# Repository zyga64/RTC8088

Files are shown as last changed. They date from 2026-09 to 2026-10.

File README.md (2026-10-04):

# RTC8088
Real Time Clock for your PC XT. Very low profile, simple and open hardware.

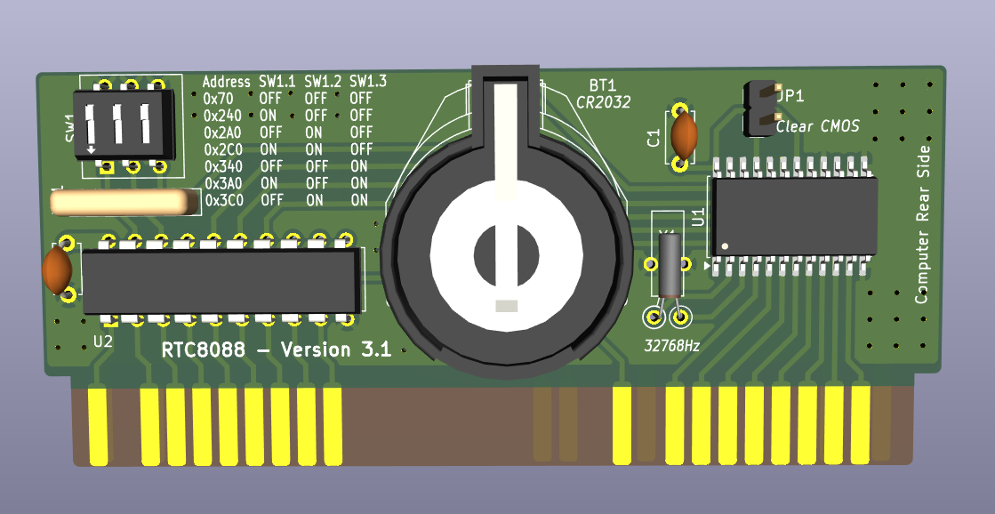
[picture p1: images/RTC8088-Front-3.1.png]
RTC8088 V3.1 3D Rendering


## Hardware Documentation

### Schematic and PCB Layout

[Schematic - Version 3.1](KiCad/RTC8088-Schematic-3.1.pdf)

### Swiches and Jumpers

#### SW1 - RTC I/O address select

I/O Address  | SW1.1 | SW 1.2 | SW 1.3
------------ | ----- | ------ | ------
0x70         | OFF   | OFF    | OFF
0x240        | ON    | OFF    | OFF
0x2A0        | OFF   | ON     | OFF
0x2C0        | ON    | ON     | OFF
0x340        | OFF   | OFF    | ON
0x3A0        | ON    | OFF    | ON
0x3C0        | OFF   | ON     | ON
Reserved     | ON    | ON     | ON

* Note 1: The table above gives the addresses in the supplied SPLD fuse map. The selection can be changed by reprogramming the SPLD
* Note 2: "Reserved" address is set to 0x70 in the supplied SPLD fuse map. It is recommended to use this setting when adding a custom I/O address to the SPLD

#### JP1 - Clear CMOS

Position       | Description
-------------- | -----------------
open (default) | Normal operation
closed         | Clear NVRAM memory

### Bill of Materials

#### Version 3.1

Component type     | Reference | Description                                     | Quantity | Possible sources and notes 
------------------ | --------- | ----------------------------------------------- | -------- | --------------------------
PCB                |           | RTC8088 PCB - Version 3.0                       | 1        | Order from your favorite PCB manufacturer using provided Gerber files
Integrated Circuit | U1        | BQ3285S - RTC, 24 pin SO -24                    | 1        | Aliexpress :)
Integrated Circuit | U2        | ATF16V8B-15PU - Simple Programmable Logic Device, 20 pin DIP | 1 | Mouser [556-AF16V8B15PU](https://www.mouser.com/ProductDetail/556-AF16V8B15PU) or GAL16V8
Quartz Crystal     | Y1        | 32768 Hz, 6 pF                                  | 1        | Mouser [815-AB26T32768KHZ6B](https://www.mouser.com/ProductDetail/815-AB26T32768KHZ6B), [520-ECS327-6-13-X](https://www.mouser.com/ProductDetail/520-ECS327-6-13-X), or [628-VT200F-6PF20PPM](https://www.mouser.com/ProductDetail/628-VT200F-6PF20PPM)
Battery Holder     | BT1       | CR2032 battery holder                           | 1        | Mouser [122-2620-GR](https://www.mouser.com/ProductDetail/122-2620-GR) or [122-2420-GR](https://www.mouser.com/ProductDetail/122-2420-GR)
Battery            | BT1       | CR2032 battery                                  | 1        | Mouser [81-CR2032](https://www.mouser.com/ProductDetail/81-CR2032), [658-CR2032](https://www.mouser.com/ProductDetail/658-CR2032), or [614-CR2032-200](https://www.mouser.com/ProductDetail/614-CR2032-200)
Capacitor          | C1,C2     | 0.1 uF, 50V, MLCC, 5 mm pitch                   | 2        | Mouser [594-K104K15X7RF53H5](https://www.mouser.com/ProductDetail/594-K104K15X7RF53H5) or [810-FG28X7R1H104KNT6](https://www.mouser.com/ProductDetail/810-FG28X7R1H104KNT6)
Resistor Array     | RN1       | 10 kohm, bussed, 5 pin SIP                      | 1        | Mouser [652-4605X-1LF-10K](https://www.mouser.com/ProductDetail/652-4605X-1LF-10K) or [652-4605X-AP1-103LF](https://www.mouser.com/ProductDetail/652-4605X-AP1-103LF)
DIP Switch         | SW1       | DIP switch, 3 position, SPST                    | 1        | Mouser [774-2103MS](https://www.mouser.com/ProductDetail/774-2103MS)
Pin Header         | JP1       | 2 pin header, 2.54 mm pitch                     | 1        | Mouser [649-68002-102HLF](https://www.mouser.com/ProductDetail/649-68002-102HLF)
Jumper             | JP1       | Shunt, 2 pin, 2.54 mm pitch                     | 1        | Mouser [806-SX1100-B](https://www.mouser.com/ProductDetail/806-SX1100-B)
IC Socket          | U2        | 20 pin DIP, 2.54 mm pitch, 7.62 mm row spacing  | 1        | Mouser [649-DILB20P-223TLF](https://www.mouser.com/ProductDetail/649-DILB20P-223TLF)

## Software

The board is supported by the [8088 BIOS](https://github.com/skiselev/8088_bios) and [GLaTICK BIOS Extension](https://github.com/640-KB/GLaTICK).

## Release Notes

### Changes

* Version 3.1
  * Change THT DS12885 to SMT BQ3285S
* Version 3.0
  * Add I/O address configuration switches
  * Remove IRQ configuration jumpers and IRQ support
* Version 2.0
  * Aitor RTC8088
* Version 1.0
  * Initial version

### Known Issues

* No known issues

### Wishlist

* None so far

## Red Tape

### Licensing

RTC8088 is an open source hardware project. The hardware design itself, including schematic and PCB layout design files are licensed under the strongly-reciprocal variant of [CERN Open Hardware Licence version 2](license-cern_ohl_s_v2.txt). The SPLD code is licensed under [GNU General Public License v3](license-gpl-3.0.txt). Documentation, including this file, is licensed under the [Creative Commons Attribution-ShareAlike 4.0 International License](license-cc-by-sa-4.0.txt).

CERN-OHL-2.0-S, GPL-3.0, CC-BY-SA-4.0

## More information

### Orignal RTC8088 Project Description
https://hackaday.io/project/168972-rtc-isa-8-bits-pcxt

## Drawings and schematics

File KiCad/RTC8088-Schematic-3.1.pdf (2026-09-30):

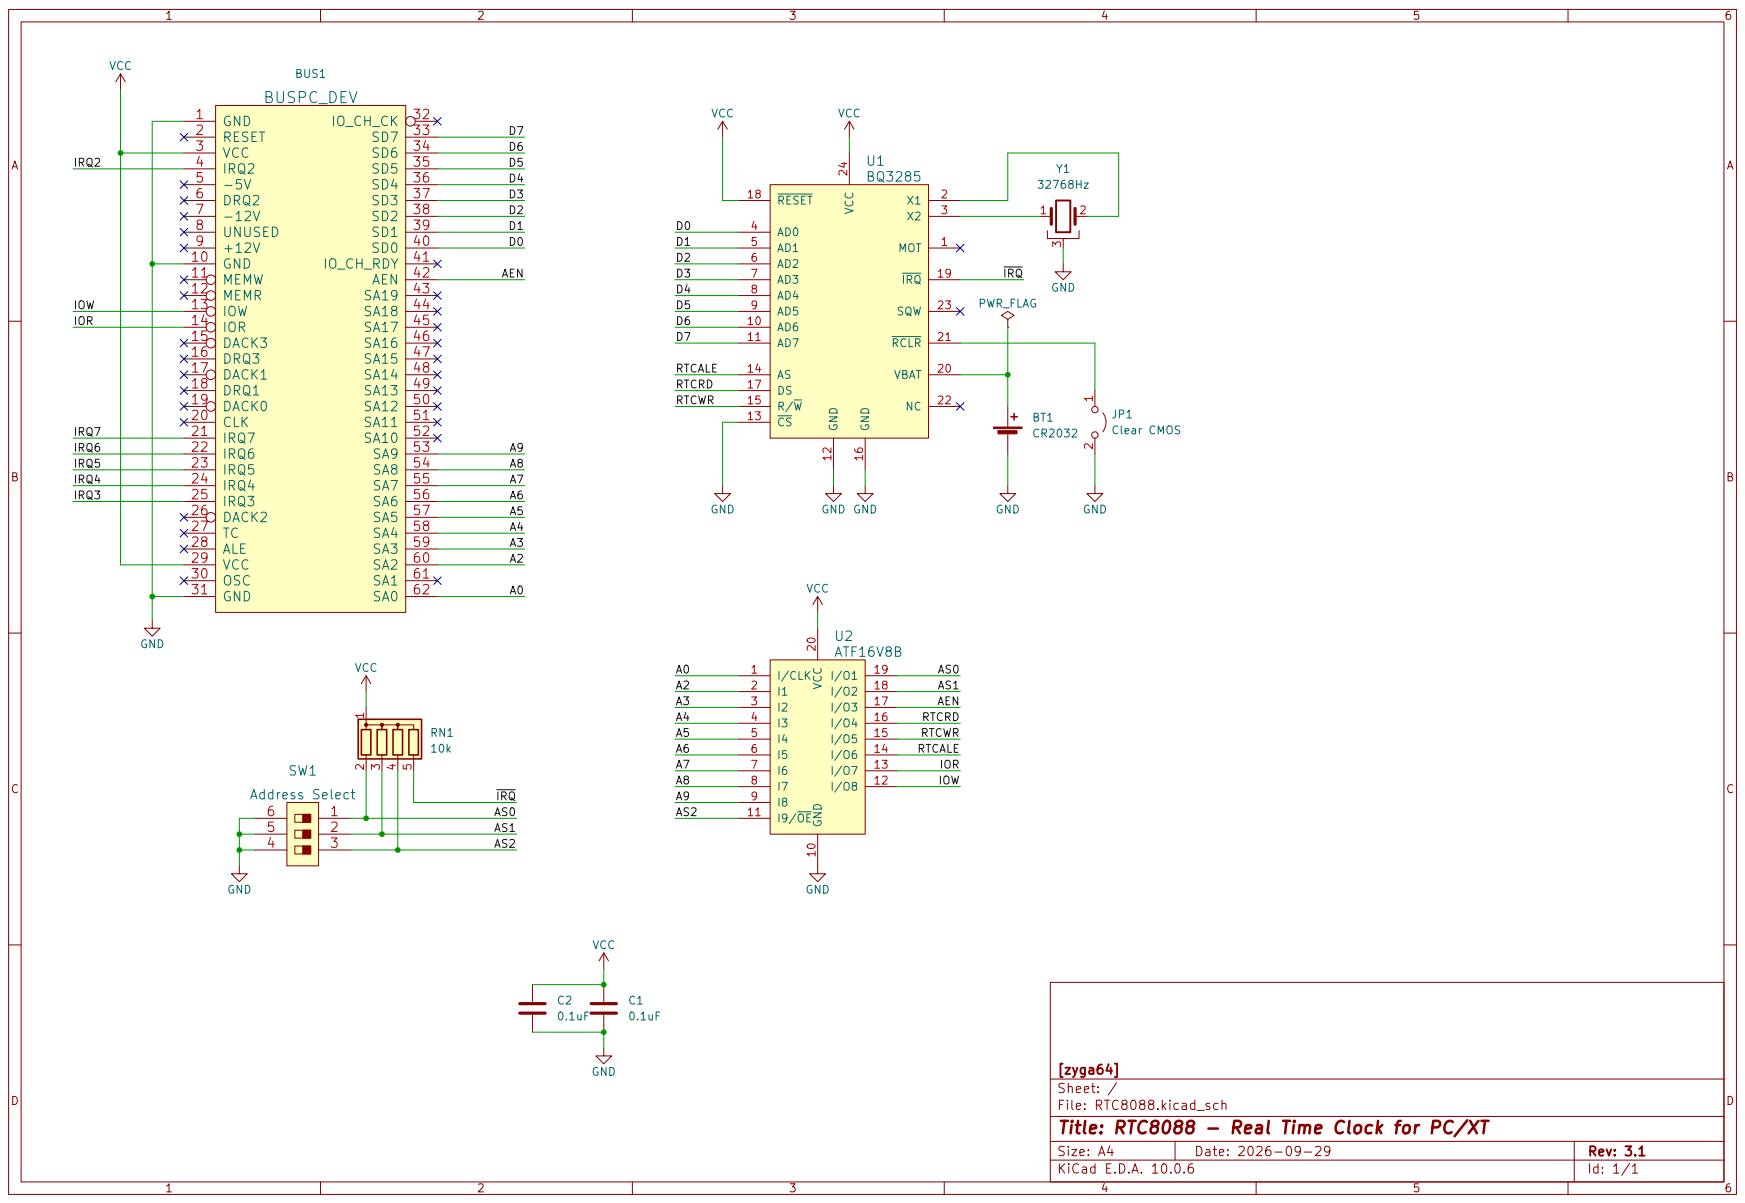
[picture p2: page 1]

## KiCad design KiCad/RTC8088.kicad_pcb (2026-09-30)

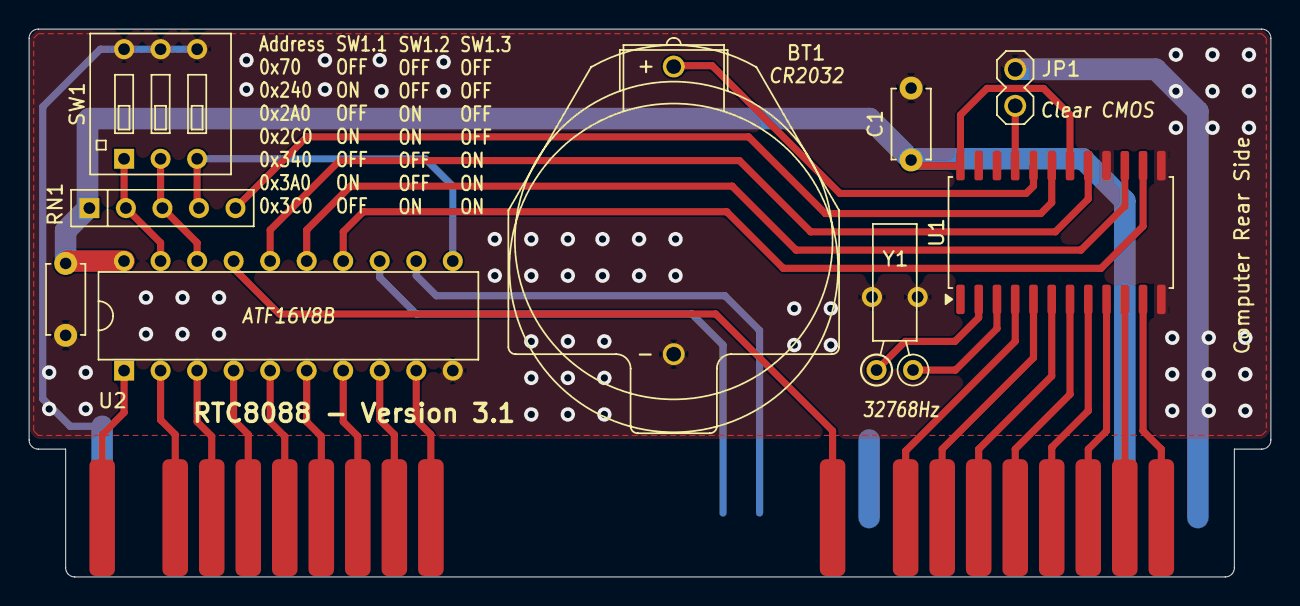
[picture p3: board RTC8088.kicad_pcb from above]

Board: 2 copper layers, 86.4 x 38.1 mm, 10 parts (0 on the bottom side), 33 nets.

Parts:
BT1: CR2032; Battery_Holder_CR2032_Universal
BUS1: BUSPC_DEV; Conn_Edge_PCB_ISA8
C1, C2: 0.1uF; C_Disc_D4.7mm_W2.5mm_P5.00mm
JP1: Clear CMOS; Conn_Pin_Header_2x1_2.54mm_NoKey
RN1: 10k; Conn_SIL5
SW1: Address Select; Switch_DIP_3_Positions
U1: DS12885; SOIC-24W_7.5x15.4mm_P1.27mm
U2: ATF16V8B; IC_DIP20_300
Y1: 32768Hz; Crystal_32K_Horiz

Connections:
/A0: BUS1.62 (SA0), U2.1 (I/CLK)
/A2: BUS1.60 (SA2), U2.2 (I1)
/A3: BUS1.59 (SA3), U2.3 (I2)
/A4: BUS1.58 (SA4), U2.4 (I3)
/A5: BUS1.57 (SA5), U2.5 (I4)
/A6: BUS1.56 (SA6), U2.6 (I5)
/A7: BUS1.55 (SA7), U2.7 (I6)
/A8: BUS1.54 (SA8), U2.8 (I7)
/A9: BUS1.53 (SA9), U2.9 (I8)
/AEN: BUS1.42 (AEN), U2.17 (I/O3)
/AS0: RN1.2 (R1), SW1.1, U2.19 (I/O1)
/AS1: RN1.3 (R2), SW1.2, U2.18 (I/O2)
/AS2: RN1.4 (R3), SW1.3, U2.11 (I9/~OE)
/D0: BUS1.40 (SD0), U1.4 (AD0)
/D1: BUS1.39 (SD1), U1.5 (AD1)
/D2: BUS1.38 (SD2), U1.6 (AD2)
/D3: BUS1.37 (SD3), U1.7 (AD3)
/D4: BUS1.36 (SD4), U1.8 (AD4)
/D5: BUS1.35 (SD5), U1.9 (AD5)
/D6: BUS1.34 (SD6), U1.10 (AD6)
/D7: BUS1.33 (SD7), U1.11 (AD7)
/IOR: BUS1.14 (IOR), U2.13 (I/O7)
/IOW: BUS1.13 (IOW), U2.12 (I/O8)
/RTCALE: U1.14 (AS), U2.14 (I/O6)
/RTCRD: U1.17 (DS), U2.16 (I/O4)
/RTCWR: U1.15 (R/~W), U2.15 (I/O5)
/~IRQ: RN1.5 (R4), U1.19 (~IRQ)
GND: BT1.2 (-), BUS1.1 (GND), BUS1.10 (GND), BUS1.31 (GND), C1.2, C2.2, JP1.2 (B), SW1.4, SW1.5, SW1.6, U1.12 (GND), U1.13 (~CS), U1.16 (GND), U2.10 (GND), Y1.3
unnamed: BT1.1 (+), U1.20 (VBAT)
unnamed: JP1.1 (A), U1.21 (~RCLR)
unnamed: U1.2 (X1), Y1.2
unnamed: U1.3 (X2), Y1.1
VCC: BUS1.3 (VCC), BUS1.29 (VCC), C1.1, C2.1, RN1.1 (common), U1.18 (~RESET), U1.24 (VCC), U2.20 (VCC)

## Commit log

2026-09-30 Replace tht DS12855 with smt bq3285
    [RTC8088-B_Cu.gbl, RTC8088-B_Cu.gbr, RTC8088-B_Mask.gbr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]
2026-09-30 Update README for Schematic and BOM to version 3.1
    Updated references from version 3.0 to 3.1 in the README.
2026-09-30 Remove 20 pin IC socket from README components
    Removed entry for 20 pin IC socket from the components list.

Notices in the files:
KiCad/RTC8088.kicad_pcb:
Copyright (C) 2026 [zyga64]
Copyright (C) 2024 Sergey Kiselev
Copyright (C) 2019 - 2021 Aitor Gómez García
